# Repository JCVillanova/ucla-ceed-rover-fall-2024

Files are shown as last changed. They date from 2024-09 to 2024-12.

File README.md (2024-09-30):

# ucla-ceed-rover-fall-2024
This is a repository for the ENGR 1AR project design course at UCLA (autonomous rover).

Team Members:

Isabel Gutierrez

Anderson Pecot

Ria Rizo

Kayleen Speller

Joshua Villanova

At the end of the fall 2024 quarter, we will have engineered and programmed a rover that is capable of navigating obstacles and moving objects to a target location.

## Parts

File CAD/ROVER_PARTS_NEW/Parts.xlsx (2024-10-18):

Parts to Order | Amount | Link | Price for each | Total Price
400 Point Bread Board | 8 | https://www.amazon.com/BB400-Solderless-BreadBoard-tie-Points-Backing/dp/B00Q9G8MQS | $5.90 | 47.2
Arduino Uno | 15 | https://www.amazon.com/ARDUINO-A000073-ATMEGA328-Original-Version/dp/B007R9TUJE | $27.37 | 410.55
Arduino Mega | 7 | https://www.amazon.com/ARDUINO-MEGA-2560-REV3-A000067/dp/B0046AMGW0 | $38.00 | 266
6V DC Motor (x4) | 2 | https://www.amazon.com/MELIFE-Motor-Gearbox-200RPM-Arduino/dp/B096ZZHJW9 | $10.98 | 21.96
12V DC Motor | 6 | https://www.amazon.com/Greartisan-Electric-Reduction-Centric-Diameter/dp/B072R57C56 | $12.99 | 6
L298N Motor Driver (x4) | 2 | https://www.amazon.com/HiLetgo-Controller-Stepper-H-Bridge-Mega2560/dp/B07BK1QL5T | $10.29 | 20.58
HC-SR04 Ultrasonic Sensor (x5) | 1 | https://www.amazon.com/SunFounder-Ultrasonic-Distance-Duemilanove-Rapsberry/dp/B00E0NXTJW | $9.89 | 9.89
HC-05 Bluetooth Module (x2) | 3 | https://www.amazon.com/HiLetgo-Bluetooth-Transceiver-Integrated-Communication/dp/B07VL725T8?s=electronics | $12.99 | 38.97
3.7V 18650 Battery | 7 | https://www.amazon.com/Veckuty-Rechargeable-Batteries-Spotlight-Flashlight/dp/B08DKW65LB?s=electronics | $20.99 | 146.93
11.1V LiPo Batteryn (x2) | 2 | https://www.amazon.com/TURNIGY-1000mAh-LIPO-Battery-Station/dp/B07ZPCL5S7 | $24.99 | 49.98
High Torque Servos | 10 | https://www.amazon.com/SunFounder-Digital-Helicopter-Fix-Wing-Airplane/dp/B01KZKOIZC | $11.99 | 119.9
MPU-6050 | unknown | https://www.amazon.com/HiLetgo-MPU-6050-Accelerometer-Gyroscope-Converter/dp/B00LP25V1A | $3.33
Total |  |  |  | 1137.96
**Quantity might be different depending on inventory/number of functional parts
Current Inventory
Wheels
Screws
Misc
Solidworks Licenses

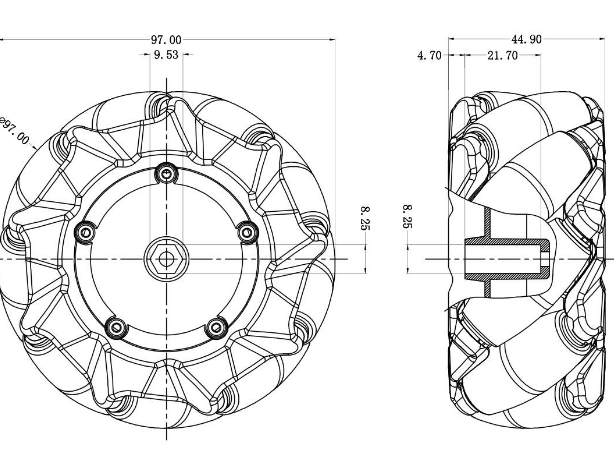
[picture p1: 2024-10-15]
CAD/Provided Parts/Mecanum-Wheel.png

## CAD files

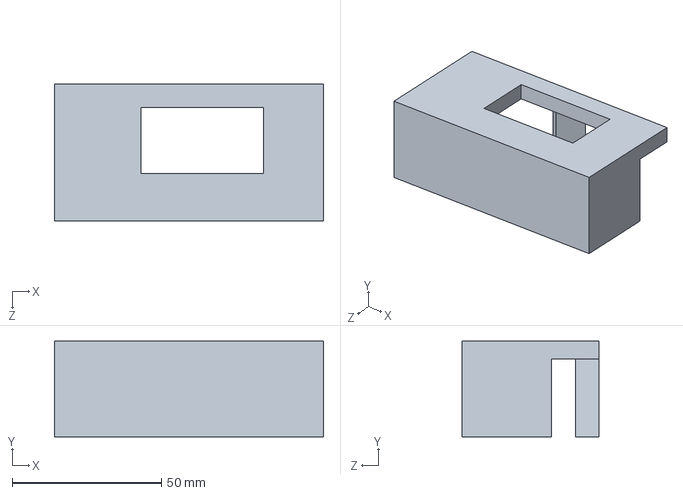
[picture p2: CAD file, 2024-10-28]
CAD/Grabber_mainholder.SLDPRT
90.0 x 32.0 x 46.0 mm

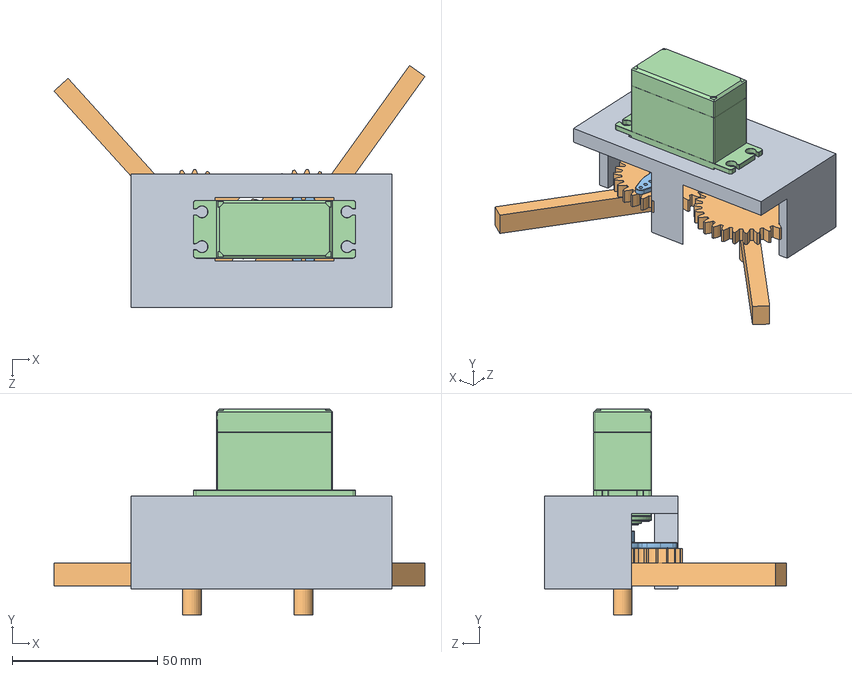
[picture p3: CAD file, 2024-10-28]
CAD/She-ray1_Grabber.SLDASM
127.9 x 71.0 x 83.5 mm
Servo Motor
ServoAttacment2
Grabber_gear1 x 2
Grabber_mainholder

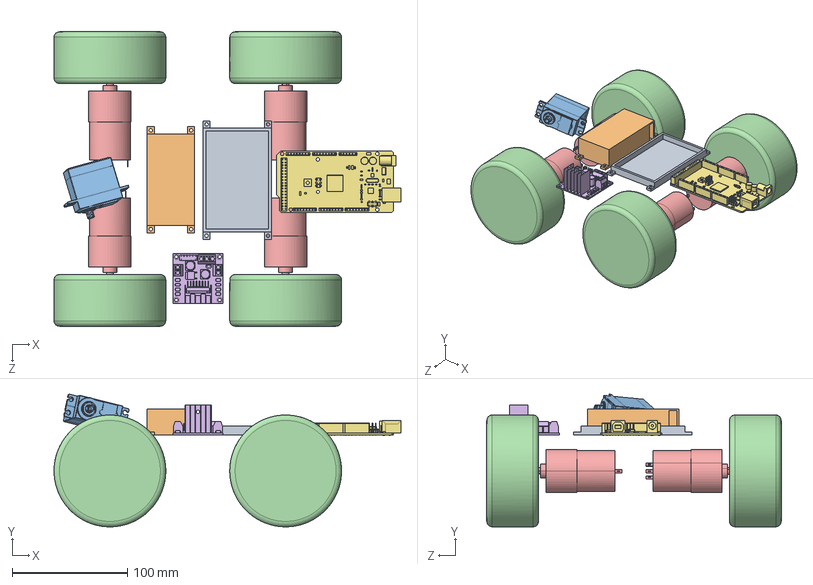
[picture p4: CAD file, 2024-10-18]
CAD/She-ray1.SLDASM
301.0 x 115.1 x 255.4 mm
ArduinoMega
L298N Motor Driver
MOTOR x 4
MecanumWheel x 4
Servo Motor
Battery Holder - Top
Bread Board Holder

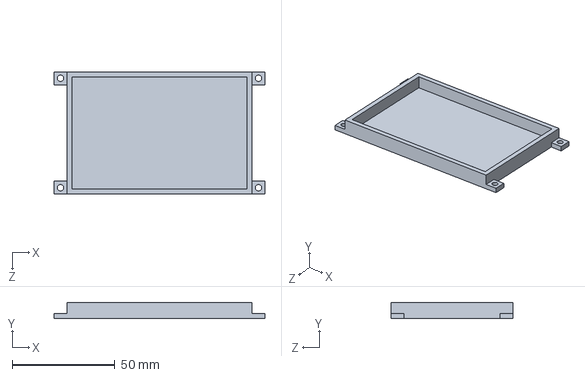
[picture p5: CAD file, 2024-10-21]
CAD/ROVER_PARTS_NEW/Bread Board Holder.SLDPRT
102.9 x 7.94 x 59.7 mm

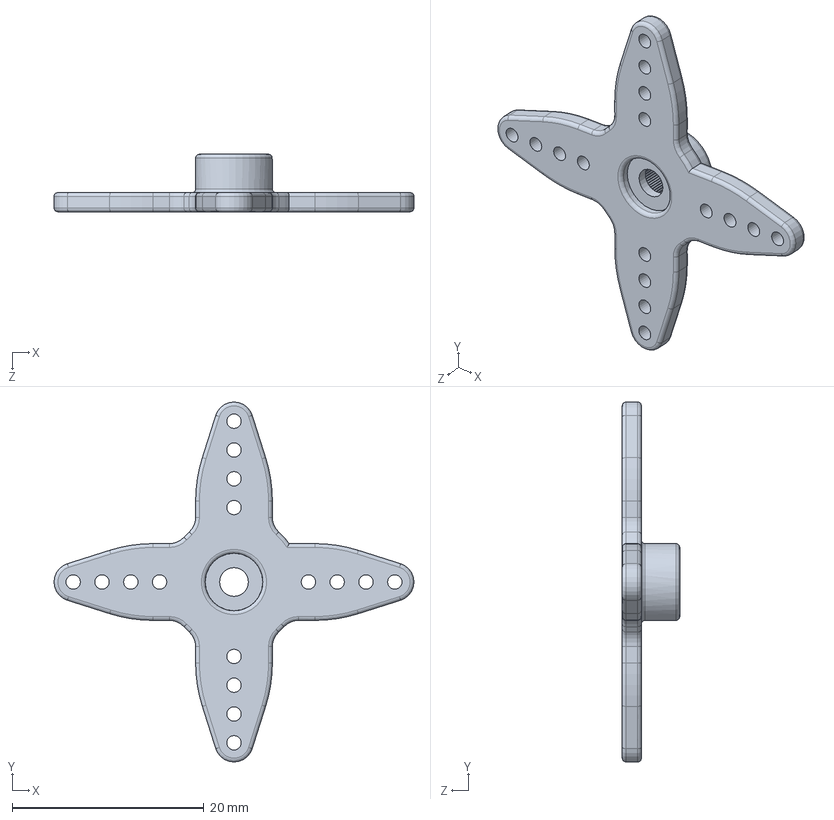
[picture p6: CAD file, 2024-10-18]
CAD/ROVER_PARTS_NEW/Servo Motor/ServoAttacment1.SLDPRT
37.5 x 37.5 x 6.00 mm

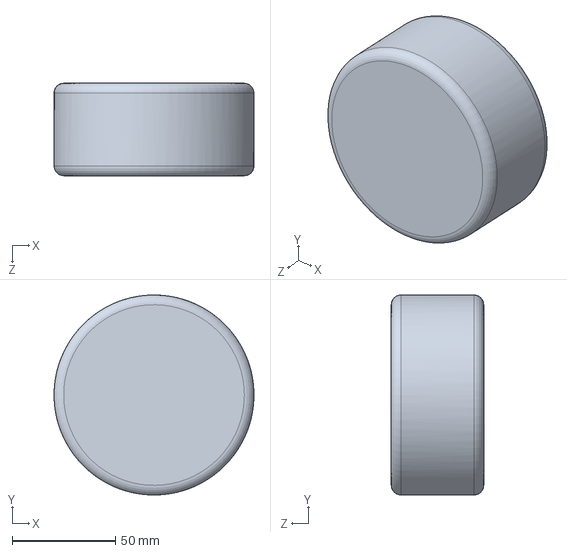
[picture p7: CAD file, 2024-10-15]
CAD/Provided Parts/MecanumWheel.SLDPRT
97.0 x 97.0 x 44.9 mm

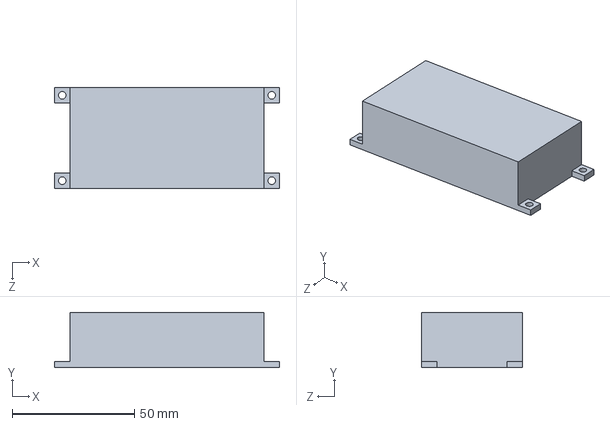
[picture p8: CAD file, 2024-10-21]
CAD/ROVER_PARTS_NEW/Battery Holder - Top.SLDPRT
92.1 x 22.5 x 41.3 mm

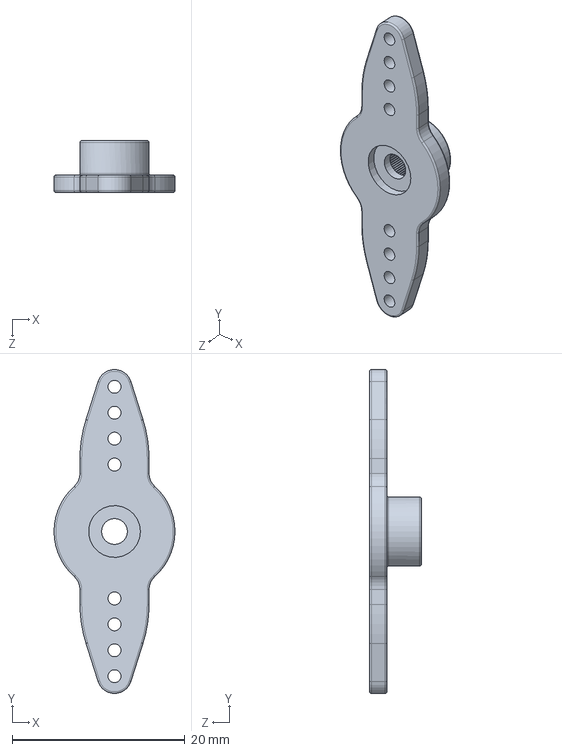
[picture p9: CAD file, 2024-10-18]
CAD/ROVER_PARTS_NEW/Servo Motor/ServoAttacment2.SLDPRT
14.0 x 37.5 x 6.00 mm

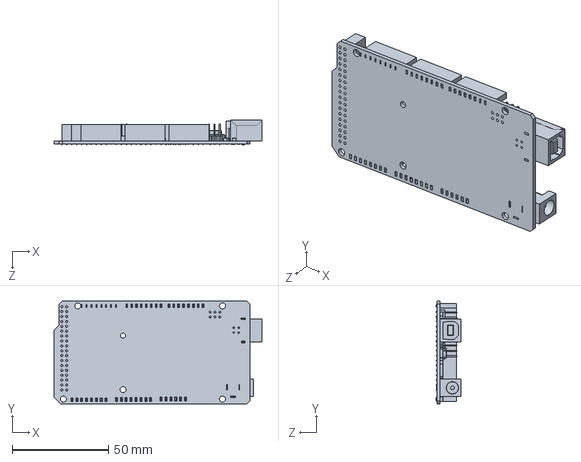
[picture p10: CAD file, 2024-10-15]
CAD/Provided Parts/ArduinoMega.SLDPRT
107.9 x 53.4 x 13.0 mm

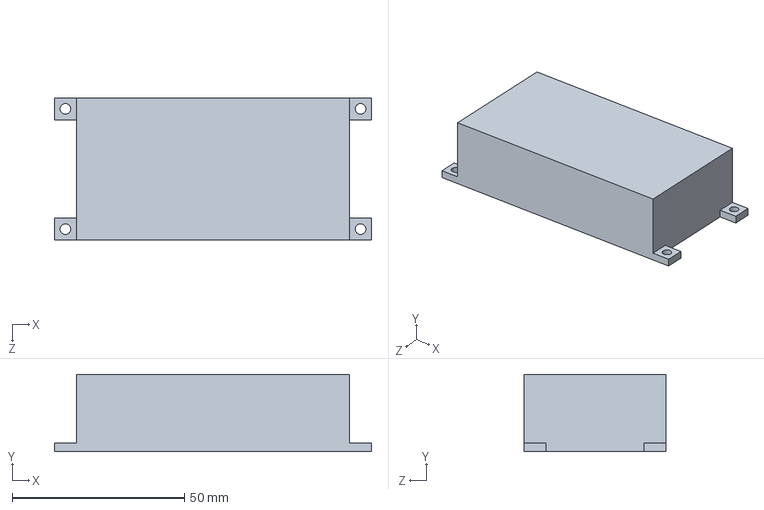
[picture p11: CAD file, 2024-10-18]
CAD/ROVER_PARTS_NEW/Battery Holder - Top_W22.SLDPRT
92.1 x 22.5 x 41.3 mm

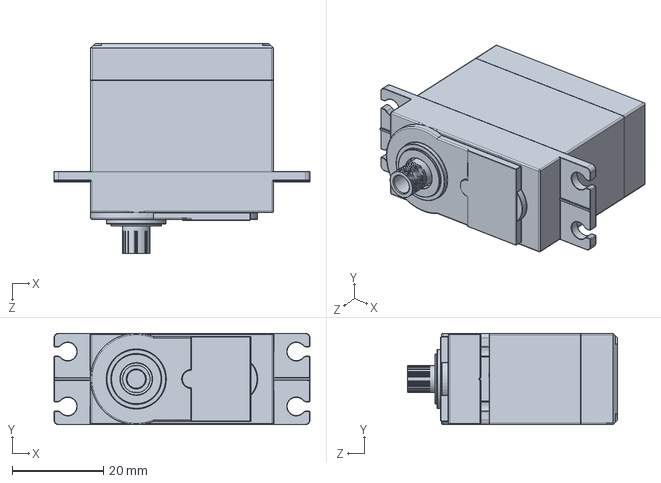
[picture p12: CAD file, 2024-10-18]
CAD/ROVER_PARTS_NEW/Servo Motor/Servo Motor.SLDPRT
56.0 x 20.0 x 46.0 mm

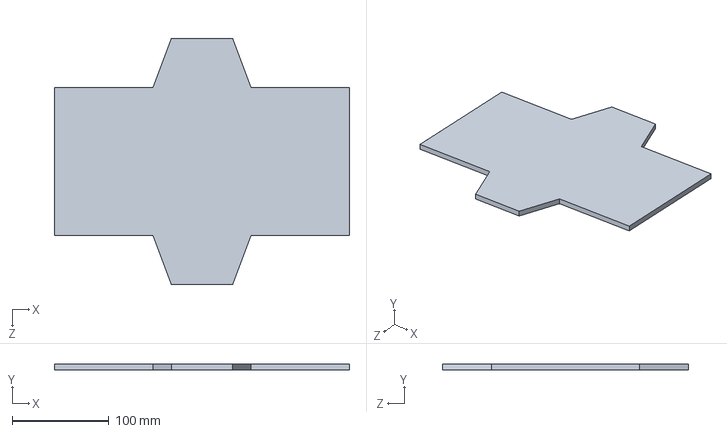
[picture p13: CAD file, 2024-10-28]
CAD/Sher-ray1_Chasis.SLDPRT
304.8 x 6.35 x 254.0 mm

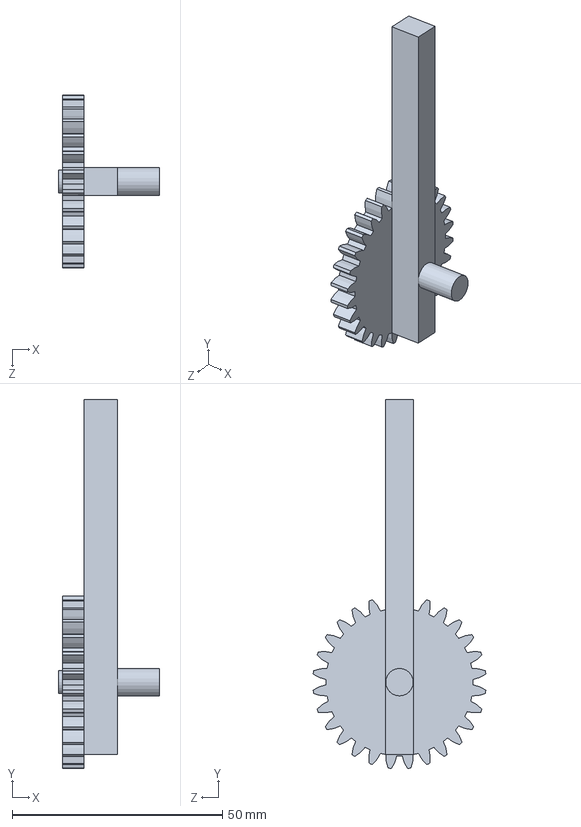
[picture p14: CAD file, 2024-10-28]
CAD/Grabber_gear1.SLDPRT
24.0 x 87.8 x 41.1 mm

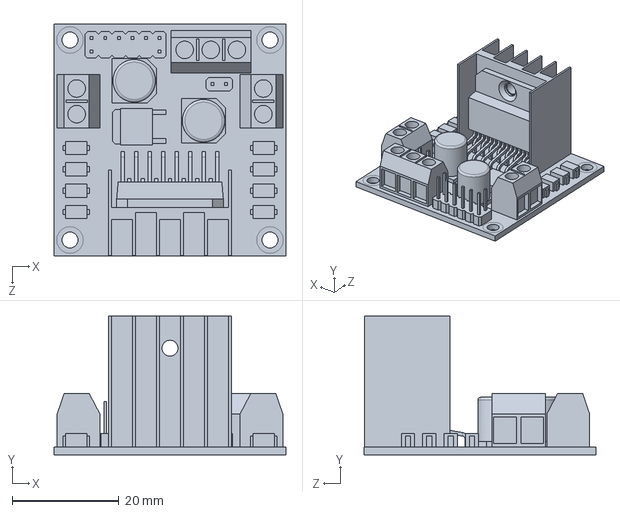
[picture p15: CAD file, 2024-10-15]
CAD/Provided Parts/L298N Motor Driver.SLDPRT
43.5 x 26.0 x 43.5 mm

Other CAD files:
CAD/Provided Parts/Sher-ray1_Chasis.SLDPRT
CAD/ROVER_PARTS_NEW/L298N.SLDPRT
CAD/Provided Parts/MOTOR.SLDPRT
CAD/ROVER_PARTS_NEW/UltrasonicHolder_(new) (1).SLDPRT
CAD/DXFs/Sher-ray1_Chasis.DXF
CAD/ENGR 1 ACT 2.SLDPRT
CAD/ROVER_PARTS_NEW/Battery Holder - Top.STL
CAD/ROVER_PARTS_NEW/Battery Holder- Bottom.SLDPRT
CAD/ROVER_PARTS_NEW/Battery Holder- Bottom.STL
CAD/ROVER_PARTS_NEW/Bread Board Holder.STL
CAD/ROVER_PARTS_NEW/Bread Board Holder_W22.SLDPRT
CAD/ROVER_PARTS_NEW/FinalRoverWheel.SLDPRT
CAD/ROVER_PARTS_NEW/Motor Clamp.SLDPRT
CAD/ROVER_PARTS_NEW/STD Servomotor.SLDPRT
CAD/ROVER_PARTS_NEW/ULTRASONIC SENSOR.SLDPRT
CAD/ROVER_PARTS_NEW/UltrasonicHolder.STL
CAD/ROVER_PARTS_NEW/Wheel_example.SLDPRT
CAD/ROVER_PARTS_NEW/motor_rough.SLDPRT
CAD/STLs/Sher-ray_SensorHolder.STL
CAD/Sher-ray_SensorHolder.SLDPRT

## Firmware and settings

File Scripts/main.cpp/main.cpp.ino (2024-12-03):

#include <NewPing.h>
#include <Wire.h>
#include <MPU6050_light.h>
#include <Servo.h>

MPU6050 mpu(Wire);

const int SENSOR_AVERAGE_RANGE = 4;

const int speed = 255;
bool sensorsSetUp = false;
bool inSearchArea = false;
bool objectPickedUp = false;
bool leftDidNotWork = false;
bool obstacleFound = false;
bool extraRotate = false;
double sensorData[6][SENSOR_AVERAGE_RANGE]; // 2D array to store sensor data values for each of 6 sensors

// Define wiring pins for Motor 1
#define leftFront_enB 2
#define leftFront_in4 3
#define leftFront_in3 4
#define leftBack_enA 5
#define leftBack_in1 6
#define leftBack_in2 7

// Define wiring pins for Motor 2
#define rightFront_enA 8
#define rightFront_in1 9
#define rightFront_in2 10
#define rightBack_enB 11
#define rightBack_in4 12
#define rightBack_in3 13

// Ultrasonic sensor
#define sonar1 25 // front left
#define sonar2 26 // front right
#define sonar3 24 // left
#define sonar4 23 // right
#define sonar5 22 // back
#define sonar6 27 // for claw
#define MAX_DISTANCE 400
#define NUM_SONAR 6

// Servo motor
#define servoPWM 44
Servo myServo;

NewPing sonar[NUM_SONAR] = { // array of ultrasonic sensors
  NewPing(sonar1, sonar1, MAX_DISTANCE),
  NewPing(sonar2, sonar2, MAX_DISTANCE),
  NewPing(sonar3, sonar3, MAX_DISTANCE),
  NewPing(sonar4, sonar4, MAX_DISTANCE),
  NewPing(sonar5, sonar5, MAX_DISTANCE),
  NewPing(sonar6, sonar6, MAX_DISTANCE)
};

int distance[NUM_SONAR]; // distance array for each sensor

// setup() method is called once when the program begins
void setup() {
  // Serial port begin
  Serial.begin(9600);
  Serial.println("Setup started");

  Wire.begin();
  
  byte status = mpu.begin();
  Serial.print(F("MPU6050 status: "));
  Serial.println(status);
  while(status!=0){ } // stop everything if could not connect to MPU6050
  
  Serial.println(F("Calculating offsets, do not move MPU6050"));
  delay(1000);
  // mpu.upsideDownMounting = true; // uncomment this line if the MPU6050 is mounted upside-down
  mpu.calcOffsets(); // gyro and accelero
  Serial.println("Done!\n");

  // Configure Motor 1 pins as outputs
  pinMode(leftFront_enB, OUTPUT);
  pinMode(leftFront_in4, OUTPUT);
  pinMode(leftFront_in3, OUTPUT);
  pinMode(leftBack_enA, OUTPUT);
  pinMode(leftBack_in1, OUTPUT);
  pinMode(leftBack_in2, OUTPUT);

  // Configure Motor 2 pins as outputs
  pinMode(rightFront_enA, OUTPUT);
  pinMode(rightFront_in1, OUTPUT);
  pinMode(rightFront_in2, OUTPUT);
  pinMode(rightBack_enB, OUTPUT);
  pinMode(rightBack_in4, OUTPUT);
  pinMode(rightBack_in3, OUTPUT);

}

// loop() method is called repeatedly as long as the program is running
void loop() {
  if(!sensorsSetUp) {
    for(int i = 0; i < SENSOR_AVERAGE_RANGE; ++i) {
      delay(40);
      updateSonar(sensorData, i);
    }

    for(int i = 0; i < NUM_SONAR; ++i) {
      for(int j = 0; j < SENSOR_AVERAGE_RANGE; ++j) {
        distance[i] += sensorData[i][j];
      }
      distance[i] /= SENSOR_AVERAGE_RANGE;
    }
    sensorsSetUp = true;
  }

  mpu.update();

  delay(40);
  updateSonar(sensorData);

  if(distance[2] + distance[3] > 150) {
    inSearchArea = true;
  }

  if(inSearchArea && !objectPickedUp) {
    for(int i = 0; i < 4; ++i) updateSonar(sensorData);
    while(distance[3] > 90) {
      goForward();
    }
    delay(750);
    stop();
    while(mpu.getAngleZ() - 85 > 5 || mpu.getAngleZ() - 85 < -5) {
      rotateLeft(128);
      mpu.update();
    }
    /*if(!extraRotate) {
      delay(1500);
      stop();
      delay(200);
      extraRotate = true;
    }*/
    if(distance[5] >= 8) {
      goBackward();
    } else {
      stop();
      delay(200);
      updateSonar(sensorData);
      if(distance[5] <= 5) {
        myServo.attach(servoPWM);
        myServo.write(0);
        delay(1500);
        objectPickedUp = true;
        Serial.println("Object was picked up");
      }
    }
  } else if(objectPickedUp) {
    rotateLeft(128);
    delay(2250);
    
    goBackward();
    delay(8000);
    stop();
    while(1);
  } else {
      if(frontDistance() <= 30) {
        if(distance[2] >= 20 && !leftDidNotWork) {
          obstacleFound = true;
          Serial.println("Going left");
          goLeft();
          if(distance[2] <= 20) leftDidNotWork = true;
        }
        else {
          Serial.println("Going right");
          goRight();
        }
      } else {
        if(obstacleFound) {
          stop();
          delay(100);
          while(mpu.getAngleZ() > 5) {
            Serial.println("Realigning right");
            rotateRight(50);
            mpu.update();
          }
          while(mpu.getAngleZ() < -5) {
            Serial.println("Realigning left");
            rotateLeft(50);
            mpu.update();
          }
          obstacleFound = false;
        }
        leftDidNotWork = false;
        Serial.println("Going forward probably");
        goForward();
      }
  }
}

// Update distance array for all sensors
void updateSonar(double sensorData[][SENSOR_AVERAGE_RANGE]) {
  double ping;
  double sum[6] = {0, 0, 0, 0, 0, 0};
  for(int i = 0; i < NUM_SONAR; ++i) {
    ping = sonar[i].ping_cm(); // store ping value

    // Shift all values left in the array, deleting the oldest value to make room for new value
    for(int j = 0; j < SENSOR_AVERAGE_RANGE - 1; ++j) {
      sensorData[i][j] = sensorData[i][j+1];
    }
    sensorData[i][SENSOR_AVERAGE_RANGE-1] = ping;

    // Add up 16 past values and average them out
    for(int k = 0; k < SENSOR_AVERAGE_RANGE; ++k) {
      sum[i] += sensorData[i][k];
    }
    sum[i] /= SENSOR_AVERAGE_RANGE;
    distance[i] = sum[i];

    //if(distance[i] == 0) distance[i] = MAX_DISTANCE;
  }
}

void updateSonar(double sensorData[][SENSOR_AVERAGE_RANGE], int index) {
  for(int i = 0; i < NUM_SONAR; ++i) {
    sensorData[i][index] = sonar[i].ping_cm();
  }
}

void printDistances() {
  for(int i = 0; i < NUM_SONAR; ++i) {
    Serial.print("Sonar ");
    Serial.print(i + 1);
    Serial.print(": ");
    Serial.println(distance[i]);
  }
}

bool obstacleTooCloseFront() {
  if(distance[0] <= 25 || distance[1] <= 25) return true;
  return false;
}

double frontDistance() {
  if(distance[0] < distance[1]) return distance[0];
  else return distance[1];
}

bool obstacleTooCloseLeft() {
  if(distance[2] <= 50) return true;
  return false;
}

bool obstacleTooCloseRight() {
  if(distance[3] <= 50) return true;
  return false;
}

// All four wheels move forward
void goForward() {
  // Set alternating voltages on each wheel's pin
  digitalWrite(leftFront_in4, LOW);
  digitalWrite(leftFront_in3, HIGH);
  digitalWrite(rightFront_in1, LOW);
  digitalWrite(rightFront_in2, HIGH);
  digitalWrite(leftBack_in1, LOW);
  digitalWrite(leftBack_in2, HIGH);
  digitalWrite(rightBack_in4, LOW);
  digitalWrite(rightBack_in3, HIGH);

  // Apply voltage to pins at previously specified voltages
  analogWrite(leftFront_enB, speed);
  analogWrite(rightFront_enA, speed);
  analogWrite(leftBack_enA, speed);
  analogWrite(rightBack_enB, speed);
}

// All four wheels move backward
void goBackward() {
  digitalWrite(leftFront_in4, HIGH);
  digitalWrite(leftFront_in3, LOW);
  digitalWrite(rightFront_in1, HIGH);
  digitalWrite(rightFront_in2, LOW);
  digitalWrite(leftBack_in1, HIGH);
  digitalWrite(leftBack_in2, LOW);
  digitalWrite(rightBack_in4, HIGH);
  digitalWrite(rightBack_in3, LOW);

  analogWrite(leftFront_enB, speed);
  analogWrite(rightFront_enA, speed);
  analogWrite(leftBack_enA, speed);
  analogWrite(rightBack_enB, speed);
}

// Left front and right back wheels move forward, right front and left back wheels move backward
void goRight() {
  digitalWrite(leftFront_in4, LOW);
  digitalWrite(leftFront_in3, HIGH);
  digitalWrite(rightFront_in1, HIGH);
  digitalWrite(rightFront_in2, LOW);
  digitalWrite(leftBack_in1, HIGH);
  digitalWrite(leftBack_in2, LOW);
  digitalWrite(rightBack_in4, LOW);
  digitalWrite(rightBack_in3, HIGH);

  analogWrite(leftFront_enB, speed);
  analogWrite(rightFront_enA, speed);
  analogWrite(leftBack_enA, speed);
  analogWrite(rightBack_enB, speed);
}

// Rotates the rover to the right
void rotateRight(int rotateSpeed) {
  digitalWrite(leftFront_in4, LOW);
  digitalWrite(leftFront_in3, HIGH);
  digitalWrite(rightFront_in1, HIGH);
  digitalWrite(rightFront_in2, LOW);
  digitalWrite(leftBack_in1, LOW);
  digitalWrite(leftBack_in2, HIGH);
  digitalWrite(rightBack_in4, HIGH);
  digitalWrite(rightBack_in3, LOW);

  analogWrite(leftFront_enB, speed);
  analogWrite(rightFront_enA, speed);
  analogWrite(leftBack_enA, speed);
  analogWrite(rightBack_enB, speed);
}

// Right front and left back wheels move forward, left front and right back wheels move backward
void goLeft() {
  digitalWrite(leftFront_in4, HIGH);
  digitalWrite(leftFront_in3, LOW);
  digitalWrite(rightFront_in1, LOW);
  digitalWrite(rightFront_in2, HIGH);
  digitalWrite(leftBack_in1, LOW);
  digitalWrite(leftBack_in2, HIGH);
  digitalWrite(rightBack_in4, HIGH);
  digitalWrite(rightBack_in3, LOW);

  analogWrite(leftFront_enB, speed);
  analogWrite(rightFront_enA, speed);
  analogWrite(leftBack_enA, speed);
  analogWrite(rightBack_enB, speed);
}

// Rotates the rover to the left
void rotateLeft(int rotateSpeed) {
  digitalWrite(leftFront_in4, HIGH);
  digitalWrite(leftFront_in3, LOW);
  digitalWrite(rightFront_in1, LOW);
  digitalWrite(rightFront_in2, HIGH);
  digitalWrite(leftBack_in1, HIGH);
  digitalWrite(leftBack_in2, LOW);
  digitalWrite(rightBack_in4, LOW);
  digitalWrite(rightBack_in3, HIGH);

  analogWrite(leftFront_enB, speed);
  analogWrite(rightFront_enA, speed);
  analogWrite(leftBack_enA, speed);
  analogWrite(rightBack_enB, speed);
}

// Right front and left back wheels move forward 
void goForwardRight() {
  digitalWrite(rightFront_in1, LOW);
  digitalWrite(rightFront_in2, HIGH);
  digitalWrite(leftBack_in1, LOW);
  digitalWrite(leftBack_in2, HIGH);

  analogWrite(leftFront_enB, 0);
  analogWrite(rightFront_enA, speed);
  analogWrite(leftBack_enA, speed);
  analogWrite(rightBack_enB, 0);
}

// Left front and right back wheels move forward 
void goForwardLeft() {
  digitalWrite(leftFront_in4, LOW);
  digitalWrite(leftFront_in3, HIGH);
  digitalWrite(rightBack_in4, LOW);
  digitalWrite(rightBack_in3, HIGH);

  analogWrite(leftFront_enB, speed);
  analogWrite(rightFront_enA, 0);
  analogWrite(leftBack_enA, 0);
  analogWrite(rightBack_enB, speed);
}

// Left front and right back wheels move backward 
void goBackwardRight() {
  digitalWrite(leftFront_in4, HIGH);
  digitalWrite(leftFront_in3, LOW);
  digitalWrite(rightBack_in4, HIGH);
  digitalWrite(rightBack_in3, LOW);

  analogWrite(leftFront_enB, speed);
  analogWrite(rightFront_enA, 0);
  analogWrite(leftBack_enA, 0);
  analogWrite(rightBack_enB, speed);
}

// Right front and left back wheels move backward 
void goBackwardLeft() {
  digitalWrite(rightFront_in1, HIGH);
  digitalWrite(rightFront_in2, LOW);
  digitalWrite(leftBack_in1, HIGH);
  digitalWrite(leftBack_in2, LOW);

  analogWrite(leftFront_enB, 0);
  analogWrite(rightFront_enA, speed);
  analogWrite(leftBack_enA, speed);
  analogWrite(rightBack_enB, 0);
}

// Set all voltages to zero, stopping the rover 
void stop() {
  analogWrite(leftFront_enB, 0);
  analogWrite(rightFront_enA, 0);
  analogWrite(leftBack_enA, 0);
  analogWrite(rightBack_enB, 0);
}

// Test any kind of movement function for a specified time 
// Takes two parameters: a pointer to a function (e.g. to goForward()), and an amount of time in milliseconds, then performs that movement for the time given
void testMovement(void (*move)(), int time) {
  move();
  delay(time);
  stop();
}

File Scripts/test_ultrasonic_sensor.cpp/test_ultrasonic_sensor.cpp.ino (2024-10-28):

#include <HCSR04.h>

#define trigPin 9
#define echoPin 8

// Ultrasonic sensor
long duration, cm, inches;

void setup() {
  // Serial port begin
  Serial.begin(9600);

  pinMode(echoPin, INPUT);
  pinMode(trigPin, OUTPUT);
}

void loop() {
  // Send 10 microsecond signal
  digitalWrite(trigPin, LOW);
  delayMicroseconds(5);
  digitalWrite(trigPin, HIGH);
  delayMicroseconds(10);
  digitalWrite(trigPin, LOW);

  duration = pulseIn(echoPin, HIGH);

  cm = (duration / 2) / 29.1;
  inches = (duration / 2) / 74.0;

  Serial.print(inches);
  Serial.print("in, ");
  Serial.print(cm);
  Serial.print("cm\n");

  delay(250);
}

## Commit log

2024-10-14 CAD Files of provided parts
    [ArduinoMega.SLDPRT, ArduinoMega_STEP_AP203.STEP, L298N Motor Driver.SLDPRT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]
2024-10-14 Create main.cpp.ino
    The file main.cpp.ino configures pins with the wiring of the rover and includes a few functions for movement and stopping, as well as testing movement.
2024-10-14 Fix compiler error in main.cpp.ino
    [main.cpp.ino]
2024-10-15 Add missing test script
    [test_backward_right_movement.cpp.ino]
2024-10-15 Sorted CAD files
    [ArduinoMega.SLDPRT, ArduinoMega_STEP_AP203.STEP, L298N Motor Driver.SLDPRT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]
2024-10-15 Organized parts for assembly
    [ArduinoMega.SLDPRT, L298N Motor Driver.SLDPRT, She-ray1.SLDASM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]
2024-10-15 Add files via upload
    practice
    [ENGR 1 ACT 2.SLDPRT]
2024-10-15 Add functions for turning left and right
    Current turn functions turn the rover about its center.
2024-10-15 Updated CAD
    [MecanumWheel.SLDPRT, MecanumWheels.SLDPRT, She-ray1.SLDASM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]
2024-10-15 Revert "Merge branch 'main' of https://github.com/JCVillanova/ucla-ceed-rover-fall-2024"
    This reverts commit a5e58c6c58f3dc5cc97f1122c7826e006ad554bc, reversing
    changes made to 7b3b9f82cfea0a77f831e587d3f93d611c97a20e.
    [main.cpp.ino]
2024-10-18 cad chassis
    [Battery Holder - Top.SLDPRT, Battery Holder - Top.STL, Battery Holder - Top_W22.SLDPRT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]
2024-10-18 CAD updated
    [She-ray1.SLDASM, Sher-ray1_Chasis.SLDPRT]
2024-10-24 Define ultrasonic sensors in main.cpp
    Add an array of NewPing objects using its respective library, each
    representing a separate ultrasonic sensor. Add a
    test_ultrasonic_sensor.cpp file that allows testing for a single
    ultrasonic sensor.
2024-10-24 Add more sensor functionality and test script
    Create function updateSonar() to update all 6 distance values, create
    test script to print those values every second. Change
    test_backward_left_movement.cpp to a more versatile test.cpp file for
    efficiency.
2024-10-24 Fix .ino file for test.cpp
    [test.cpp.ino]
2024-11-13 Strengthen sensor reading effectiveness
    Add algorithm to store some number of past sensor readings and average
    the values to eliminate noise in readings, passing the averaged value to
    the rover's movement script.
    [main.cpp.ino]
2024-11-25 add basic MPU6050 and servo motor function
2024-11-25 fix infinite search area problem
    [main.cpp.ino]
2024-11-25 fix infinite search area problem(2)
    [main.cpp.ino]
2024-11-25 fix infinite search area problem(3)
    [main.cpp.ino]
2024-11-25 fix infinite search area problem(4)
    [main.cpp.ino]
2024-11-26 Add helpful debugging print statements
    Also fix minor logical error in rotation to drop zone
    [main.cpp.ino]
